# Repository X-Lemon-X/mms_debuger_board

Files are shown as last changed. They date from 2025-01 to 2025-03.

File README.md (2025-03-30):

 
## Board  debug for ModualCard system Rj45 connector
### Input
- 12V xt30 connector
- USB-C connector for MMS<-PC communication USB 2.0 compatible
- CAN1 and CAN2 molex microfit 2x2 connectors.
- 2x can termination switches
- Reverse polarity protection
### Output
- Rj45 connector for ModualCard system

### RJ45 Pinout
| Pin | Function | Description |
|-----|---|---|
| 1 | CAN1 L | CAN 1 Low speed up to 1 Mb/s |
| 2 | CAN1 H | CAN 1 High speed up to 1 Mb/s |
| 3 | GND | 500mA |
| 4 | CAN2 L | CAN 2 Low speed up to 5 Mb/s |
| 5 | CAN2 H | CAN 2 High speed up to 5 Mb/s |
| 6 | 12V | 500 mA |
| 7 | USB D- | USB data plus |
| 8 | USB D+ | USB data minus |

### Images
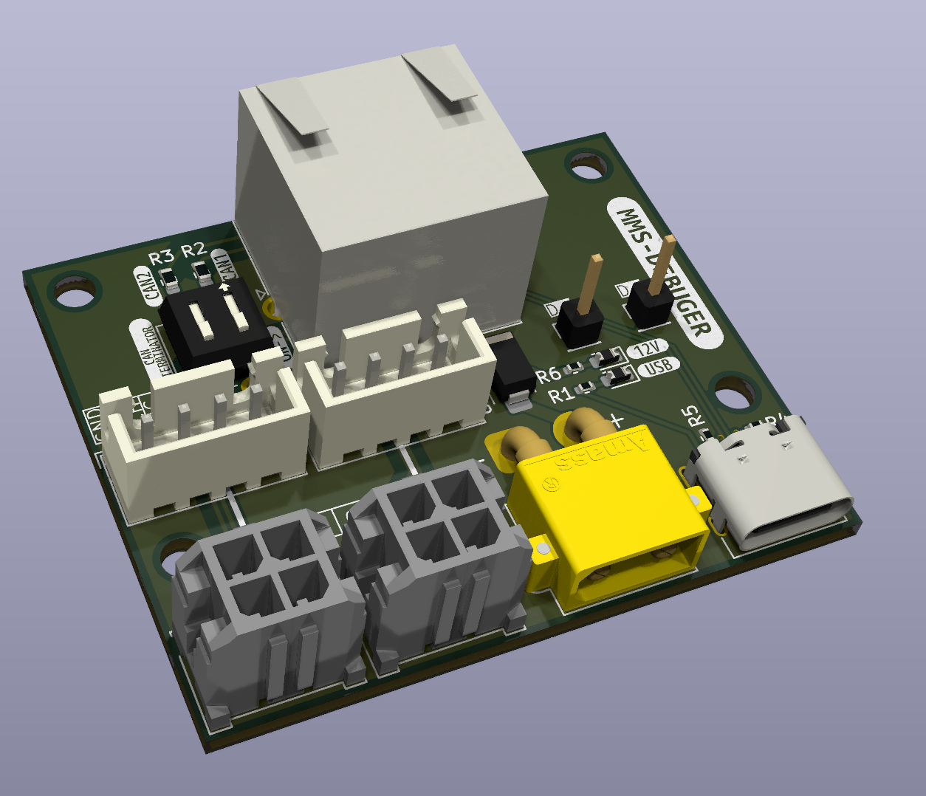
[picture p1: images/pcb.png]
Board


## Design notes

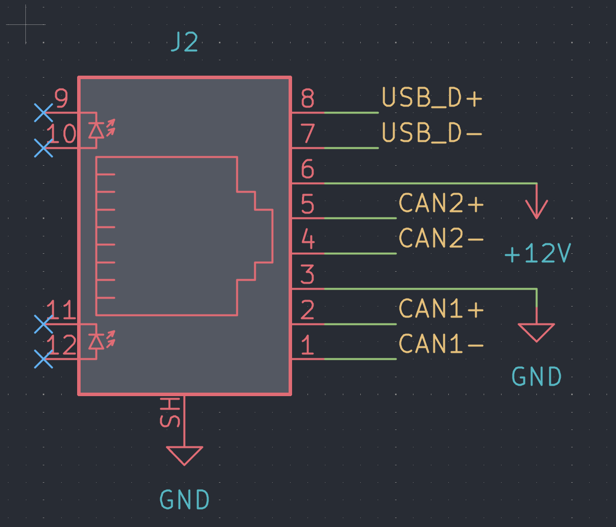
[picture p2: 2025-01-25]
images/rj45_pinout.png

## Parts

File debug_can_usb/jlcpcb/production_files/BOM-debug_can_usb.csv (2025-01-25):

Comment | Designator | Footprint | LCSC | Quantity
SW_DIP_x02 | SW1 | SW_DIP_SPSTx02_Slide_6.7x6.64mm_W7.62mm_P2.54mm_LowProfile |  | 1
120R | R2 | R_0603_1608Metric |  | 1
120R | R3 | R_0603_1608Metric |  | 1
Conn_01x01_Pin | J4 | PinHeader_1x01_P2.54mm_Vertical |  | 1
USB_C_Receptacle_USB2.0 | J5 | USB_C_Receptacle_G-Switch_GT-USB-7010ASV |  | 1
1k | R6 | R_0402_1005Metric |  | 1
Conn_01x01_Pin | J6 | PinHeader_1x01_P2.54mm_Vertical |  | 1
4k7 | R5 | R_0402_1005Metric |  | 1
Conn_01x04 | J1 | JST_XH_B4B-XH-A_1x04_P2.50mm_Vertical |  | 1
RJ45_LED_Shielded | J2 | RJ45_Amphenol_RJHSE538X |  | 1
Conn_01x04 | J3 | JST_XH_B4B-XH-A_1x04_P2.50mm_Vertical |  | 1
ss34 | D3 | D_SMA |  | 1
220 | R1 | R_0402_1005Metric |  | 1
LV_PWR | D2 | D_0603_1608Metric |  | 1
LV_PWR | D1 | D_0603_1608Metric |  | 1
CAN | U3 | Molex_Micro-Fit_3.0_43045-0412_2x02_P3.00mm_Vertical |  | 1
CAN | U2 | Molex_Micro-Fit_3.0_43045-0412_2x02_P3.00mm_Vertical |  | 1
4k7 | R4 | R_0402_1005Metric |  | 1
Conn_01x02 | J7 | AMASS_XT30PW-M_1x02_P2.50mm_Horizontal |  | 1

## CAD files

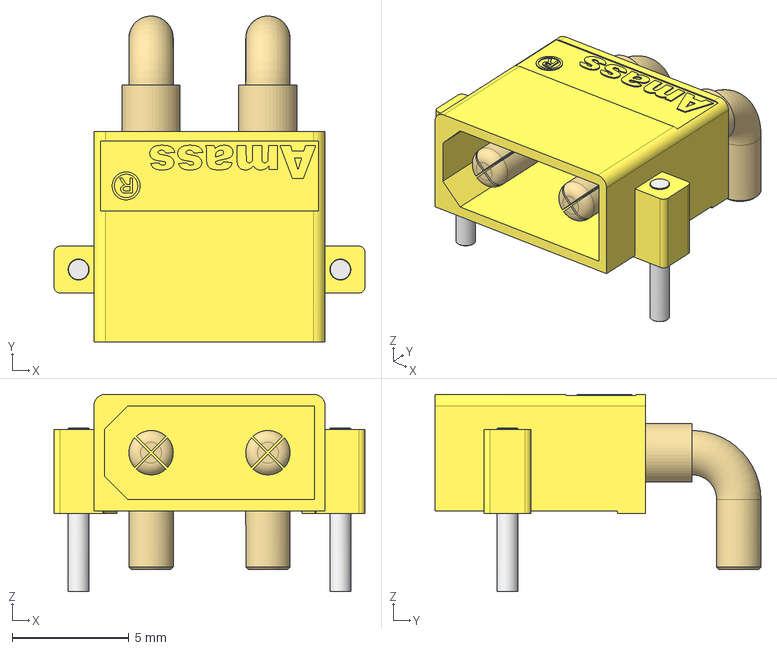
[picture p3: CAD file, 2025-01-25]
parts/3d/Amass_XT30PW-M_pcb solder.stp
13.3 x 13.9 x 8.45 mm

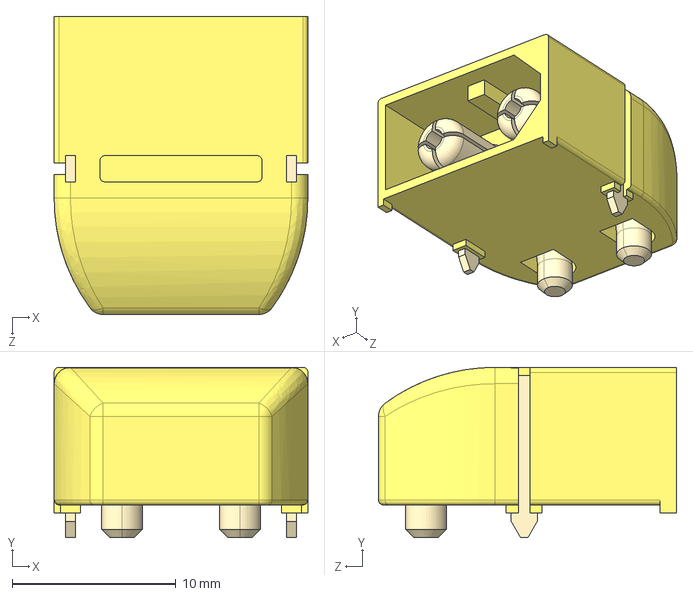
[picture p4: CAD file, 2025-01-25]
parts/3d/XT60PW MALE.STEP
15.5 x 10.4 x 18.2 mm

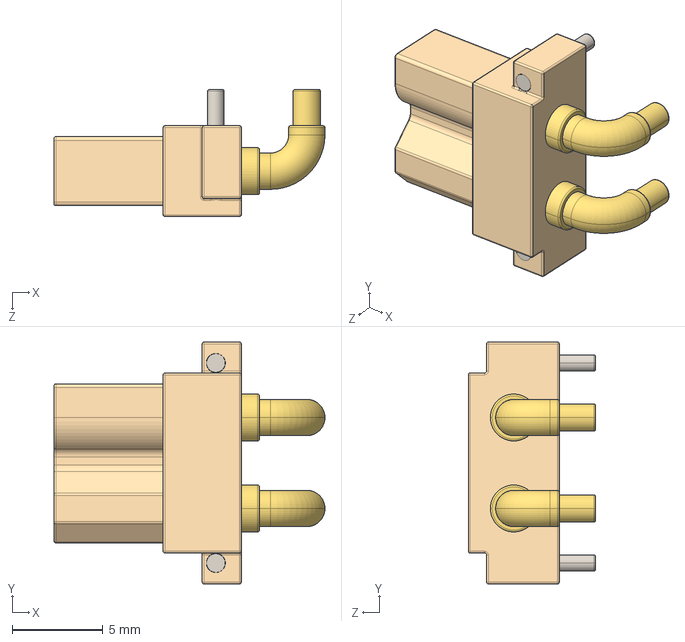
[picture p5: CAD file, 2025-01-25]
parts/3d/XT30PW-F.STEP
14.9 x 13.3 x 7.00 mm

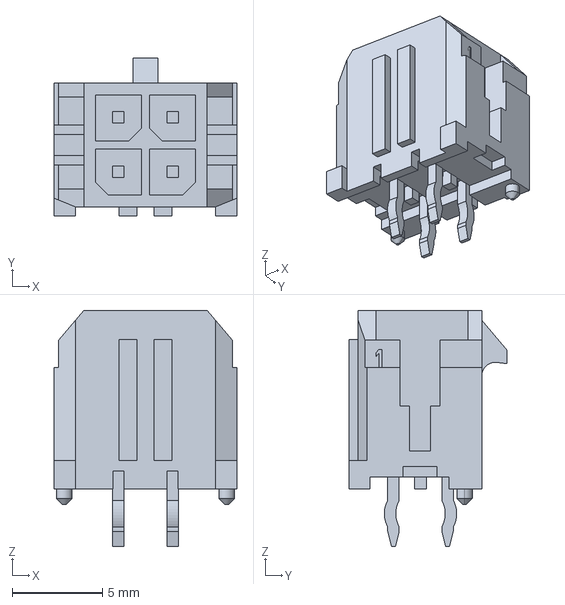
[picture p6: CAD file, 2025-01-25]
parts/3d/430450412.stp
10.2 x 8.77 x 13.1 mm

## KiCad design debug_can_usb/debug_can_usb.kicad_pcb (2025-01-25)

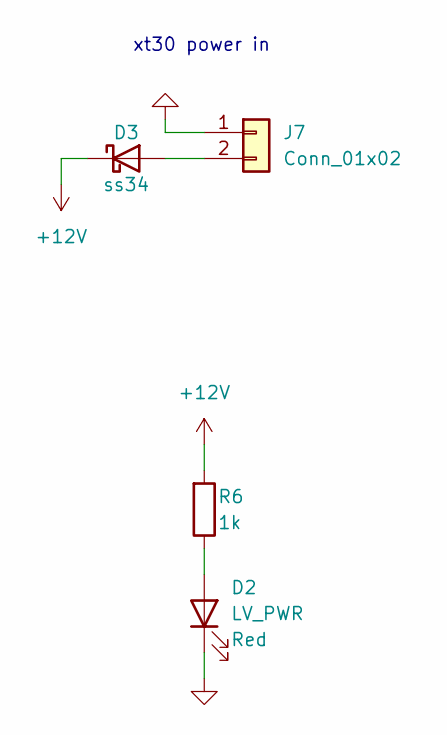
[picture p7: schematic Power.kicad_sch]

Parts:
D2: LV_PWR; D_0603_1608Metric
D3: ss34; D_SMA
J7: Conn_01x02; AMASS_XT30PW-M_1x02_P2.50mm_Horizontal
R6: 1k; R_0402_1005Metric

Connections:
+12V: D3.1 (K), R6.2; also elsewhere on the board
GND: D2.1 (K), J7.1; also elsewhere on the board
unnamed: D2.2 (A), R6.1
unnamed: D3.2 (A), J7.2

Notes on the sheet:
xt30 power in

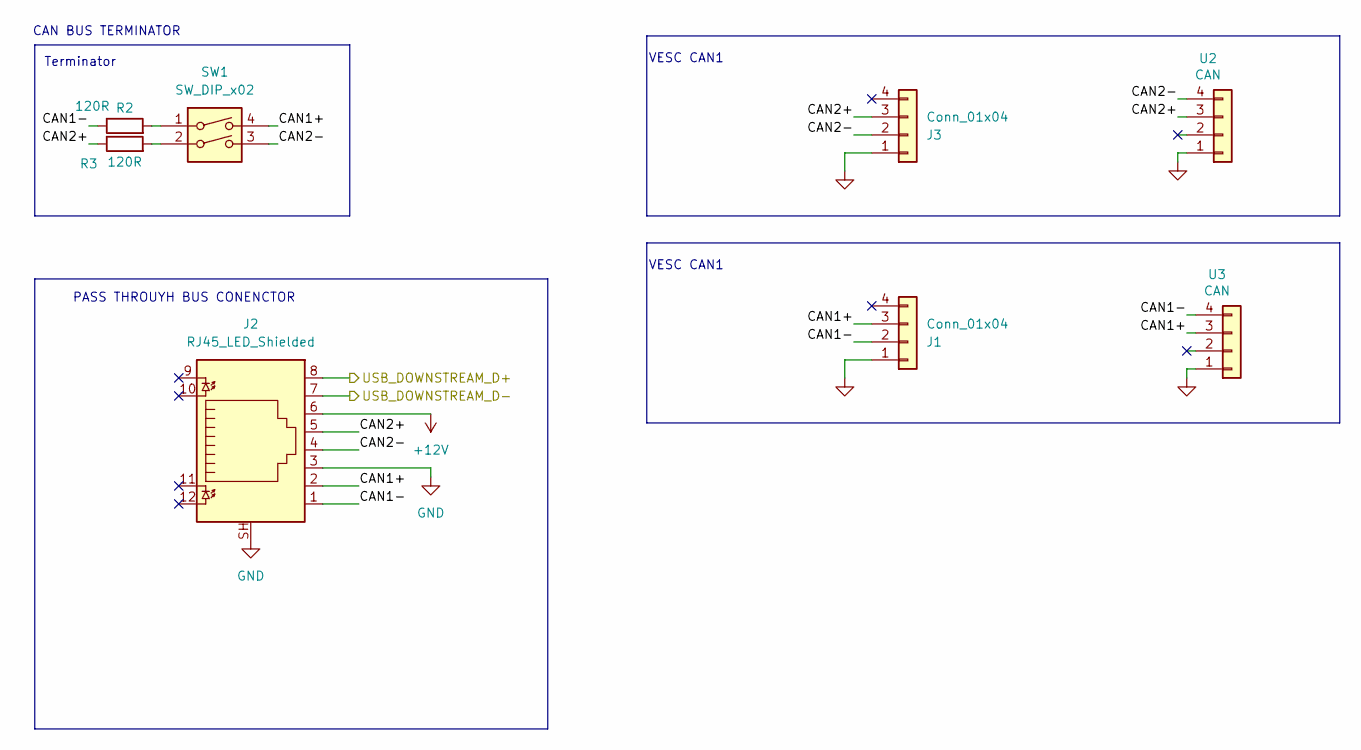
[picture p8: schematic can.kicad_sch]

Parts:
J1, J3: Conn_01x04; JST_XH_B4B-XH-A_1x04_P2.50mm_Vertical
J2: RJ45_LED_Shielded; RJ45_Amphenol_RJHSE538X
R2, R3: 120R; R_0603_1608Metric
SW1: SW_DIP_x02; SW_DIP_SPSTx02_Slide_6.7x6.64mm_W7.62mm_P2.54mm_LowProfile
U2, U3: CAN; Molex_Micro-Fit_3.0_43045-0412_2x02_P3.00mm_Vertical

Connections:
+12V: J2.6; also elsewhere on the board
/CAN/CAN1+: J1.3, J2.2, SW1.4, U3.3
/CAN/CAN1-: J1.2, J2.1, R2.1, U3.4
/CAN/CAN2+: J2.5, J3.3, R3.1, U2.3
/CAN/CAN2-: J2.4, J3.2, SW1.3, U2.4
/CAN/USB_DOWNSTREAM_D+: J2.8; also elsewhere on the board
/CAN/USB_DOWNSTREAM_D-: J2.7; also elsewhere on the board
GND: J1.1, J2.3, J2.SH, J3.1, U2.1, U3.1; also elsewhere on the board
unnamed: R2.2, SW1.1
unnamed: R3.2, SW1.2

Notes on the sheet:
PASS THROUYH BUS CONENCTOR
CAN BUS TERMINATOR
VESC CAN1
Terminator

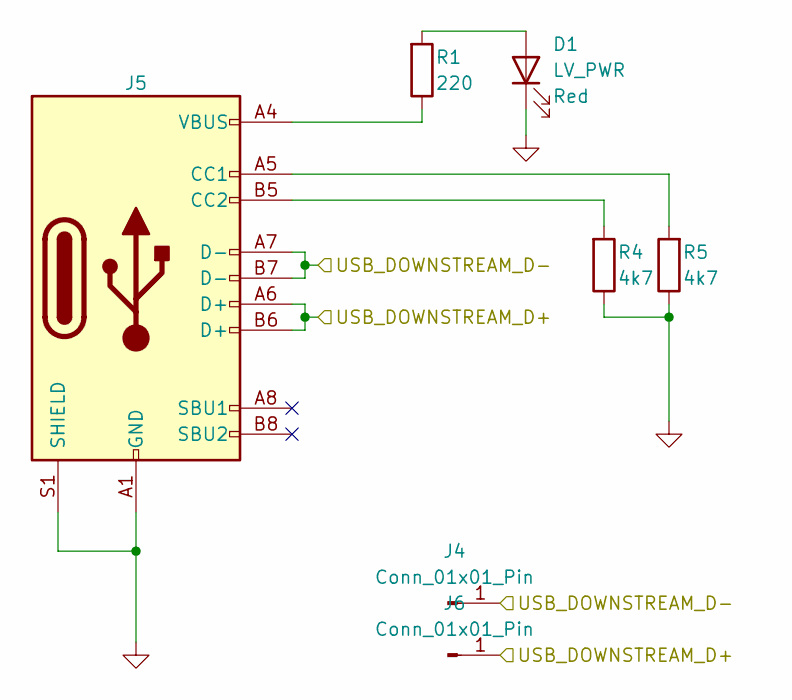
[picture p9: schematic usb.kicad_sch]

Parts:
D1: LV_PWR; D_0603_1608Metric
J4, J6: Conn_01x01_Pin; PinHeader_1x01_P2.54mm_Vertical
J5: USB_C_Receptacle_USB2.0; USB_C_Receptacle_G-Switch_GT-USB-7010ASV
R1: 220; R_0402_1005Metric
R4, R5: 4k7; R_0402_1005Metric

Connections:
/CAN/USB_DOWNSTREAM_D+: J5.A6 (D+), J5.B6 (D+), J6.1; also elsewhere on the board
/CAN/USB_DOWNSTREAM_D-: J4.1, J5.A7 (D-), J5.B7 (D-); also elsewhere on the board
GND: D1.1 (K), J5.A1 (GND), J5.A12 (GND), J5.B1 (GND), J5.B12 (GND), J5.S1 (SHIELD), R4.1, R5.1; also elsewhere on the board
unnamed: D1.2 (A), R1.2
unnamed: J5.A5 (CC1), R5.2
unnamed: J5.B5 (CC2), R4.2
unnamed: J5.A4 (VBUS), J5.A9 (VBUS), J5.B4 (VBUS), J5.B9 (VBUS), R1.1

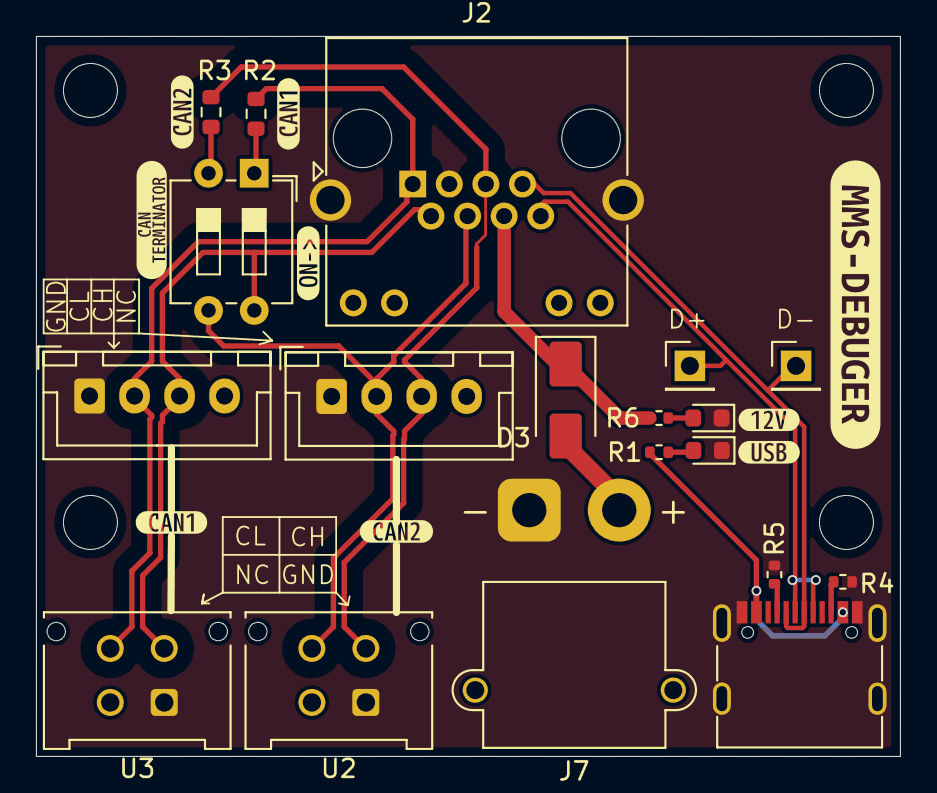
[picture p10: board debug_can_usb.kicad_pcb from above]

Board: 2 copper layers, 48.0 x 40.0 mm, 28 parts (0 on the bottom side), 16 nets.

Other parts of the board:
kibuzzard-675D9C7D, kibuzzard-675D9C7D#2: G***; kibuzzard-675D9C7D
kibuzzard-675D9C73, kibuzzard-675D9C73#2: G***; kibuzzard-675D9C73
kibuzzard-675D9CCD: G***; kibuzzard-675D9CCD
kibuzzard-67840A5C: G***; kibuzzard-67840A5C
kibuzzard-67840A66: G***; kibuzzard-67840A66
kibuzzard-67840BAA: G***; kibuzzard-67840BAA
kibuzzard-6784102F: G***; kibuzzard-6784102F
